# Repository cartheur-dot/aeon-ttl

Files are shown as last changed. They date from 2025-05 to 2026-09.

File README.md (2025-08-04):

## aeon-ttl

The most beautiful machine not only for its pure simplicity.

### References

* RAM[7400](https://github.com/emotional-toys/RAM7400)
* ideal-game-[ttl](https://github.com/emotional-toys/ideal-game-ttl)

### Endeavor

A design for a state-determinate system worthy of what started in September 2023 [here](/Starting.md).

### Relations

This repo is a part of the initiatives described in [this](https://github.com/emotional-toys/RAM7400) repository.

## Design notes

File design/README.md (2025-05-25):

## The aeon-ttl design

Words.

## Build of Materials

An estimate of the first-pass in the design is thus.

| Item # | Component | Part Number | Quantity | Description | Approx. Unit Cost (USD) | Approx. Total Cost (USD) |
|:---:|:---:|:---:|:---:|:---:|:---:|:---:|
| 1 | SRAM (4-bit) | 2114N or equivalent | 1 | 1024x4-bit SRAM (using 16 addresses) | $2.50 | $2.50 |
| 2 | 4-bit Counter | 74LS161 | 1 | Synchronous 4-bit binary counter | $0.80 | $0.80 |
| 3 | 4-bit Register | 74LS173 | 1 | 4-bit D-type register | $1.00 | $1.00 |
| 4 | 555 Timer | NE555P | 1 | Timer IC for clock generation | $0.50 | $0.50 |
| 5 | NAND Gate IC | 74LS00 | 1 | Quad 2-input NAND gate for control logic | $0.60 | $0.60 |
| 6 | AND Gate IC | 74LS08 | 1 | Quad 2-input AND gate for control logic | $0.60 | $0.60 |
| 7 | Inverter IC | 74LS04 | 1 | Hex inverter for control logic | $0.50 | $0.50 |
| 8 | D Flip-Flop | 74LS74 | 1 | Dual D flip-flop for read/write toggle | $0.60 | $0.60 |
| 9 | SPST Switch | Generic | 5 | Single-pole single-throw switches (4 for data input, 1 for R/W) | $0.30 | $1.50 |
| 10 | LED | Generic (Red) | 4 | Indicator LEDs for 4-bit data output | $0.10 | $0.40 |
| 11 | Resistor (10kΩ) | Generic | 5 | Pull-down resistors for switches | $0.05 | $0.25 |
| 12 | Resistor (330Ω) | Generic | 4 | Current-limiting resistors for LEDs | $0.05 | $0.20 |
| 13 | Capacitor (0.1µF) | Generic | 2 | Decoupling capacitors for ICs | $0.10 | $0.20 |
| 14 | Capacitor (10µF)  | Generic | 1 | Timing capacitor for 555 timer | $0.15 | $0.15 |
| 15 | Resistor (1kΩ) | Generic | 2 | Timing resistors for 555 timer | $0.05 | $0.10 |
| 16 | Power Supply | Generic | 1 | 5V DC power supply or regulator (e.g., 7805) | $1.00 | $1.00 |
| 17 | Breadboard | Generic | 1 | Prototyping board for assembly | $5.00 | $5.00 |
| 18 | Jumper Wires | Generic | 50 | Connecting wires for breadboard | $0.05 | $2.50 |

Total Estimated Cost: $16.90.

### Adding base-5 to the mix

* IC1: 2114 SRAM (1024x4-bit, 18-pin DIP).
* IC2: 74LS173 (4-bit D-type register).
* IC3: NE555 (timer for 1 kHz clock).
* IC4: 74LS00 (quad 2-input NAND).
* IC5: 74LS08 (quad 2-input AND).
* IC6: 74LS04 (hex inverter).
* IC7–IC10: 74LS47 (BCD-to-7-segment decoders, 4 units).
* IC11–IC12: 74LS157 (quad 2-to-1 multiplexers, 2 units).
* IC13: 27C16 (2Kx8 ROM for base-5 conversion).
* SW1–SW8: SPST switches (address input, A0–A7).
* SW9–SW12: SPST switches (data input, D0–D3).
* SW13: SPST switch (read/program, R/W).
* SW14: SPST switch (address/data display select).
* LED1–LED12: LEDs (8 yellow for address, 4 orange for data).
* DISP1–DISP4: Common-anode 7-segment displays.
* R1–R13: 10 kΩ resistors (pull-down for switches).
* R14–R25: 330 Ω resistors (LED current-limiting).
* R26–R27: 1 kΩ resistors (555 timer).
* C1: 0.68 µF capacitor (555 timer for 1 kHz).
* C2–C4: 0.1 µF capacitors (decoupling for ICs).
* C5: 10 µF capacitor (555 timer).
* PWR: 5V DC power supply.

| Components | On-Hand |
|:---:|:---:|
| IC1: 2114 SRAM (1024x4-bit, 18-pin DIP). | X |
| IC2: 74LS173 (4-bit D-type register). | |
| IC3: NE555 (timer for 1 kHz clock). | X |
| IC4: 74LS00 (quad 2-input NAND). | X |
| IC5: 74LS08 (quad 2-input AND). | X |
| IC6: 74LS04 (hex inverter). | X |
| IC7–IC10: 74LS47 (BCD-to-7-segment decoders, 4 units).  | |
| IC11–IC12: 74LS157 (quad 2-to-1 multiplexers, 2 units). | |
| IC13: 27C16 (2Kx8 ROM for base-5 conversion). | X |
| SW1–SW8: SPST switches (address input, A0–A7). | X |
| SW9–SW12: SPST switches (data input, D0–D3). | X |
| SW13: SPST switch (read/program, R/W). | X |
| SW14: SPST switch (address/data display select). | X |
| LED1–LED12: LEDs (8 yel for address, 4 oran for data).  | X |
| DISP1–DISP4: Common-anode 7-segment displays. | X |
| R1–R13: 10 kΩ resistors (pull-down for switches). | X |
| R14–R25: 330 Ω resistors (LED current-limiting). | X |
| R26–R27: 1 kΩ resistors (555 timer). | X |
| C1: 0.68 µF capacitor (555 timer for 1 kHz). | |
| C2–C4: 0.1 µF capacitors (decoupling for ICs). | X |
| C5: 10 µF capacitor (555 timer). | X |
| PWR: 5V DC power supply. | X |

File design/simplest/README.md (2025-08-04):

## Simplest of them all

### References

* RAM[7400](https://github.com/emotional-toys/RAM7400)
* ideal-game-[ttl](https://github.com/emotional-toys/ideal-game-ttl)

### The state-determinate system

_Summary_

* Handles 4-bit data (D0–D3) with 8-bit addressing (A0–A7) using a single 2114 RAM (1K x 4-bit).
* Uses a 1 kHz clock from a 555 timer, pausable via an SPST switch for debugging.
* Features SPST switches for 8-bit address (A0–A7), 4-bit data (D0–D3), and read/write control.
* Displays 4-bit data on LEDs (input during write, output during read).
* Uses a LOAD pushbutton to trigger read/write operations.
* Uses 74LS00 for debouncing the LOAD button (no 74LS132 available).
* Minimizes ICs: 2114, 74LS244, 555 timer, 74LS00 (4 ICs total).

Key Changes from [this](/design/PROCESS.md)

* Reverts to single 2114 RAM for 4-bit data (D0–D3), as you specified only enough SPST switches for 4-bit data.
* Adds SPST pause switch for the 555 timer (controls reset pin).
* Continues using 74LS00 for debouncing, with the same circuit as before.
* Uses eight SPST switches for addressing (A0–A7), four SPST switches for data (D0–D3), one SPST for read/write, and one pushbutton for LOAD.
* 74LS244 buffers only 4-bit data (uses half the IC, leaving the second buffer set unused).

_Build of materials_

| Component |  Quantity | Description | Notes |
|:---:|:---:|:---:|:---:|
| 2114 RAM | 1 | 1K x 4-bit static RAM (18-pin DIP) | Stores 4-bit data (D0–D3) |
| 74LS244 | 1 | Octal buffer/line driver (20-pin DIP) | Buffers 4-bit data (D0–D3) |
| 555 Timer | 1 | Timer IC (8-pin DIP) | Generates 1 kHz clock, pausable |
| 74LS00 | 1 | Quad 2-input NAND gate (14-pin DIP) | Debounces LOAD button, generates control signals |
| SPST Switches | 14 | Single-pole single-throw switches | 8 address (A0–A7), 4 data (D0–D3), 1 R/W', 1 pause |
| Pushbutton (LOAD) | 1 | Momentary SPST pushbutton | Triggers read/write operation |
| LEDs | 4 | Standard LEDs (e.g., 5mm, red) | Display 4-bit data (D0–D3) |
| Resistors (10 kΩ) | 14 | Pull-down/pull-up resistors | 8 address, 4 data, 1 R/W', 1 pause, 2 debounce |
| Resistors (220 Ω) | 4 | Current-limiting resistors for LEDs | Limit LED current to ~20 mA |
| Resistor (1 kΩ) | 1 | For 555 timer (R1) | Sets 1 kHz clock frequency |
| Resistor (680 kΩ) | 1 | For 555 timer (R2) | Sets 1 kHz clock frequency |
| Capacitor (1 µF) | 1 | For 555 timer | Sets 1 kHz clock frequency |
| Capacitor (0.1 µF)  | 3 | Decoupling (2) and debounce (1) | For U1, U2/U3/U4, and LOAD button |
| Capacitor (0.01 µF) | 1 | For 555 timer control | Stabilizes timer operation |
| Power Supply | 1 | +5V DC power supply | Powers all ICs and LEDs |

_Notes_

For KiCad, the DigiKey site has the 2114 listed as MD2114AL3. Models are [here](https://github.com/cartheur-forks/digikey-kicad-library).

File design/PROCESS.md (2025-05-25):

# 8-Bit Addressing, 4-Bit Data SRAM Interface Schematic and ROM Contents

This document describes a schematic for a digital logic circuit that interfaces an 8-bit address, 4-bit data system with SRAM, using SPST switches for input, LEDs for state indication, a 1 kHz clock, a read/program switch, and a four 7-segment display for base-5 output. It also specifies the ROM contents for binary-to-base-5 conversion to drive the display.

## Design Specifications
- **Addressing**: 8-bit address bus (256 locations) via 8 SPST switches.
- **Data**: 4-bit data bus via 4 SPST switches.
- **RAM**: 4-bit SRAM (e.g., 2114, using 256 of 1024 locations).
- **Indicators**: 12 LEDs (8 for address, 4 for data) to show binary state (0 or 1).
- **Display**: Four 7-segment displays showing address (0–255) or data (0–15) in base-5, selected by an SPST switch.
- **Control**: Read/program SPST switch for read/write operations.
- **Clock**: 1 kHz from a 555 timer for synchronous operation.

## Schematic Description

### Components
From the updated Bill of Materials (BoM):

| Item | Component | Part Number | Quantity | Description |
|---|---|---|---|---|
| IC1 | SRAM (4-bit) | 2114N | 1 | 1024x4-bit SRAM (using 256 addresses) |
| IC2 | 4-bit Register | 74LS173 | 1 | 4-bit D-type register for data |
| IC3 | 555 Timer | NE555P | 1 | Timer IC for 1 kHz clock |
| IC4 | NAND Gate IC | 74LS00 | 1 | Quad 2-input NAND for control logic |
| IC5 | AND Gate IC | 74LS08 | 1 | Quad 2-input AND for control logic |
| IC6 | Inverter IC | 74LS04 | 1 | Hex inverter for control logic |
| IC7–IC10 | BCD-to-7-Segment Decoder | 74LS47 | 4 | Decoders for base-5 display |
| IC11–IC12 | Multiplexer | 74LS157 | 2 | Quad 2-to-1 multiplexers for address/data display switch |
| IC13 | ROM | 27C16 | 1 | 2Kx8 ROM for binary-to-base-5 conversion |
| SW1–SW8 | SPST Switch | Generic | 8 | Address input (A0–A7) |
| SW9–SW12 | SPST Switch | Generic | 4 | Data input (D0–D3) |
| SW13 | SPST Switch | Generic | 1 | Read/program (R/W) |
| SW14 | SPST Switch | Generic | 1 | Address/data display select |
| LED1–LED12 | LED (Red) | Generic | 12 | LEDs for 8 address, 4 data lines |
| R1–R13 | Resistor (10 kΩ) | Generic | 13 | Pull-down resistors for switches |
| R14–R25 | Resistor (330 Ω) | Generic | 12 | Current-limiting resistors for LEDs |
| C1 | Capacitor (0.68 µF) | Generic | 1 | Timing capacitor for 555 timer (1 kHz) |
| C2–C4 | Capacitor (0.1 µF) | Generic | 3 | Decoupling capacitors for ICs |
| C5 | Capacitor (10 µF) | Generic | 1 | Timing capacitor for 555 timer |
| R26–R27 | Resistor (1 kΩ) | Generic | 2 | Timing resistors for 555 timer |
| PWR | Power Supply | Generic | 1 | 5V DC power supply |
| DISP1–DISP4 | 7-Segment Display | Generic | 4 | Common-anode displays for base-5 output |

**Total Estimated Cost**: ~$31.50 (based on 2025 prices from DigiKey/Mouser).

### Connections

1. **Power and Ground**:
   - Connect Vcc (5V) and GND to all ICs:
     - **IC1 (2114)**: Pin 18 (Vcc), Pin 9 (GND).
     - **IC2 (74LS173)**: Pin 16 (Vcc), Pin 8 (GND).
     - **IC3 (NE555)**: Pin 8 (Vcc), Pin 1 (GND).
     - **IC4 (74LS00)**: Pin 14 (Vcc), Pin 7 (GND).
     - **IC5 (74LS08)**: Pin 14 (Vcc), Pin 7 (GND).
     - **IC6 (74LS04)**: Pin 14 (Vcc), Pin 7 (GND).
     - **IC7–IC10 (74LS47)**: Pin 16 (Vcc), Pin 8 (GND).
     - **IC11–IC12 (74LS157)**: Pin 16 (Vcc), Pin 8 (GND).
     - **IC13 (27C16)**: Pin 24 (Vcc), Pin 12 (GND).
   - Place 0.1 µF capacitors (C2–C4) between Vcc and GND near IC1, IC2, and IC13.

2. **Address Input (SW1–SW8)**:
   - Connect 8 SPST switches (SW1–SW8) to 5V (ON = 1) or GND via 10 kΩ resistors (R1–R8) for A0–A7.
   - Outputs to:
     - **IC1 (2114)**: A0–A7 (Pins 1–8).
     - **LED1–LED8**: Anodes via 330 Ω resistors (R14–R21); cathodes to GND.
     - **IC11–IC12 (74LS157)**: Inputs A0–A7 (IC11: Pins 2, 5, 11, 14; IC12: Pins 2, 5, 11, 14).

3. **Data Input/Output (SW9–SW12, IC2, LED9–LED12)**:
   - Connect 4 SPST switches (SW9–SW12) to 5V or GND via 10 kΩ resistors (R9–R12) for D0–D3.
   - Outputs to **IC2 (74LS173)**: D0–D3 (Pins 3, 4, 5, 6).
   - IC2 Q0–Q3 (Pins 14, 13, 12, 11) to:
     - **IC1 (2114)**: D0–D3 (Pins 10–13).
     - **LED9–LED12**: Anodes via 330 Ω resistors (R22–R25); cathodes to GND.
     - **IC11 (74LS157)**: Inputs B0–B3 (Pins 3, 6, 12, 15).
   - IC2 clock (Pin 7) to IC3 (NE555) Pin 3.
   - Tie IC2 OE1, OE2 (Pins 9, 10) to GND; clear (Pin 15) to 5V.

4. **Clock (IC3)**:
   - Configure **IC3 (NE555)** in astable mode (~1 kHz):
     - Pin 2 (TRIG), Pin 6 (THR) to C1 (0.68 µF) to GND.
     - Pin 6 to Pin 7 (DISCH) via R26 (1 kΩ).
     - Pin 7 to 5V via R27 (1 kΩ).
     - Pin 5 (CONT) to C5 (10 µF) to GND.
     - Pin 3 (OUT) to IC2 Pin 7 and control logic.
   - Frequency: f ≈ 1.44 / ((R26 + 2×R27) × C1) ≈ 1 kHz.

5. **Control Logic (IC4, IC5, IC6, SW13)**:
   - Connect **SW13** (read/program) to 5V (read = 1) or GND via R13 (program = 0).
   - **Write Enable (WE)**:
     - SW13 to **IC4 (74LS00)** Pin 1.
     - IC3 Pin 3 to IC4 Pin 2.
     - IC4 Pin 3 to **IC1 (2114)** WE (Pin 17, active low).
   - **Output Enable (OE)**:
     - SW13 to **IC6 (74LS04)** Pin 1.
     - IC6 Pin 2 to **IC5 (74LS08)** Pin 1.
     - IC3 Pin 3 to IC5 Pin 2.
     - IC5 Pin 3 to **IC1 (2114)** OE (Pin 15, active low).
   - **Chip Enable (CE)**: Tie IC1 Pin 16 to GND (always active).

6. **Display (IC7–IC10, IC11–IC12, IC13, DISP1–DISP4, SW14)**:
   - **Address/Data Select**:
     - **SW14** to 5V (address = 1) or GND (data = 0) via 10 kΩ resistor.
     - SW14 to **IC11–IC12 (74LS157)** select pins (Pin 1).
   - **Address Inputs**:
     - SW1–SW8 (A0–A7) to IC11–IC12 inputs A0–A7.
   - **Data Inputs**:
     - IC2 Q0–Q3 to IC11 inputs B0–B3; tie IC12 B4–B7 to GND.
   - **Multiplexer Outputs**:
     - IC11–IC12 Y0–Y7 to **IC13 (27C16)** A0–A7 (Pins 2, 3, 4, 5, 6, 7, 8, 9).
   - **ROM**:
     - IC13 D0–D7 (Pins 11, 13, 15–20) to **IC7–IC10 (74LS47)** BCD inputs (A–D, Pins 7, 1, 2, 6).
     - Tie IC13 A8–A10 (Pins 10, 21, 23), CE (Pin 22), OE (Pin 20) to GND.
   - **7-Segment Displays**:
     - IC7–IC10 outputs a–g to DISP1–DISP4 segments a–g (optional 330 Ω resistors).
     - DISP1–DISP4 common anodes to 5V.
     - Tie IC7–IC10 LT (Pin 3), BI (Pin 4), RBI (Pin 5) to 5V.

## Operation
- **Write**:
  - Set SW1–SW8 (e.g., 00000011 = 3), SW9–SW12 (e.g., 1011 = 11), SW13 to program (0).
  - Clock pulse: WE = Low, OE = High; 1011 written to RAM at address 3.
  - LED1–LED8 show 00000011, LED9–LED12 show 1011.
  - SW14 selects address (2010 in base-5) or data (30 in base-5) on DISP1–DISP4.
- **Read**:
  - Set SW1–SW8 (e.g., 00000011), SW13 to read (1).
  - Clock pulse: WE = High, OE = Low; RAM outputs 1011 to IC2.
  - LED1–LED8 show 00000011, LED9–LED12 show 1011.
  - SW14 selects address (2010 in base-5) or data (30 in base-5) on DISP1–DISP4.

## ROM Contents for Base-5 Conversion
The **27C16 ROM** (2Kx8) converts 8-bit binary inputs (0–255) to base-5 digits for the four 7-segment displays. Data (0–15) requires two digits (00–30); addresses (0–255) require four digits (0000–2010).

### Conversion Logic
- **Data (0–15)**: Maps to base-5 00–30 (e.g., 15 = 3×5¹ + 0 = 30).
- **Address (0–255)**: Maps to base-5 0000–2010 (e.g., 255 = 2×5³ + 0×5² + 1×5¹ + 0 = 2010).
- Each ROM address outputs two BCD digits (8 bits: D7–D4 = digit 1, D3–D0 = digit 0).
- Use two ROM accesses per address input:
  - Address N (0x00–0xFF): Outputs digits d₁, d₀.
  - Address N+256 (0x100–0x1FF): Outputs digits d₃, d₂.

### ROM Table (Partial)
| ROM Address (Hex) | Input (Binary) | Base-5 Value | Output (BCD, D7–D0) | Display Digits |
|---|---|---|---|---|
| 00 | 00000000 (0) | 00 | 0000 0000 | 0 0 |
| 01 | 00000001 (1) | 01 | 0000 0001 | 0 1 |
| 02 | 00000010 (2) | 02 | 0000 0010 | 0 2 |
| ... | ... | ... | ... | ... |
| 0F | 00001111 (15)  | 30 | 0011 0000 | 3 0 |
| 10 | 00010000 (16)  | 31 | 0011 0001 | 3 1 |
| ... | ... | ... | ... | ... |
| FF | 11111111 (255) | 2010 | 0010 0000 | 2 0* |
| 100 | 00000000 (0) | 00 | 0000 0000 | 0 0 |
| ... | ... | ... | ... | ... |
| 1FF | 11111111 (255) | 2010 | 0001 0000 | 1 0* |

*Note*: For addresses, ROM[0xFF] gives digits 1–2 (20), ROM[0x1FF] gives digits 3–4 (10). Toggle A8 (IC13 Pin 10) via control logic or a switch to select digit pairs.

### Programming the ROM
- **Size**: Use 512 bytes (0x00–0x1FF) of the 27C16’s 2048 bytes.
- **Algorithm**:
  - For input N (0–255):
    - Compute base-5: N = d₃×5³ + d₂×5² + d₁×5¹ + d₀×5⁰ (d₀–d₃ = 0–4).
    - Store d₁, d₀ as BCD in ROM[N].
    - Store d₃, d₂ as BCD in ROM[N+256].
  - Example: N = 255 → 2010 (base-5):
    - d₃ = 2, d₂ = 0, d₁ = 1, d₀ = 0.
    - ROM[0xFF] = 0010 0000 (2 0).
    - ROM[0x1FF] = 0001 0000 (1 0).
- **Tool**: Use a programmer (e.g., TL866II) to burn the ROM. Generate the 512-byte binary file with a script (e.g., Python):

```python
rom = bytearray(512)
for n in range(256):
    d3 = n // 125  # 5^3
    n %= 125
    d2 = n // 25   # 5^2
    n %= 25
    d1 = n // 5    # 5^1
    d0 = n % 5     # 5^0
    rom[n] = (d1 << 4) | d0
    rom[n + 256] = (d3 << 4) | d2
with open("rom.bin", "wb") as f:
    f.write(rom)

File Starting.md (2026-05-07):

## A 4-Bit Logical Revolver with SRAM

This document describes a 4-bit logic system, known as a _revolver_ with memory, serving as the backplane of an embodied intelligent system. In summary: Satisfation of the linear behavior matrix construct for artificial (and real) self-contained systems.

## Circuit Overview
The circuit uses a 4-bit counter to generate addresses, a 4-bit register for data input/output, and logic gates for control signals. It operates synchronously with a clock for proper timing.

## Components
1. **RAM Chip**:
   - **Example**: 2114 SRAM (1024x4-bit, using only 16 addresses).
   - **Specs**: 4-bit data bus, 10-bit address bus (using 4 bits), control signals (CE, WE, OE).
2. **4-Bit Binary Counter**:
   - **Example**: 74LS161 (synchronous 4-bit binary counter).
   - **Purpose**: Generates 4-bit addresses (A0–A3) for 16 memory locations.
3. **4-Bit Data Register**:
   - **Example**: 74LS173 (4-bit D-type register).
   - **Purpose**: Holds data for writing to RAM or stores data read from RAM.
4. **Clock Source**:
   - **Example**: 555 timer or crystal oscillator (e.g., 1 MHz).
   - **Purpose**: Synchronizes the counter and register.
5. **Control Logic**:
   - **Components**: 74LS00 (quad NAND gates), 74LS08 (quad AND gates).
   - **Purpose**: Generates control signals (CE, WE, OE) based on read/write selector.
6. **Read/Write Selector**:
   - **Example**: Manual switch or 74LS74 D flip-flop.
   - **Purpose**: Selects read or write operation.
7. **Input Switches**:
   - Four SPST switches for 4-bit data input.
   - **Purpose**: Sets data to write to RAM.
8. **Output Display**:
   - **Example**: Four LEDs or 7-segment display with 74LS47 decoder.
   - **Purpose**: Displays 4-bit data read from RAM.
9. **Pull-up/down Resistors**:
   - **Example**: 10kΩ resistors.
   - **Purpose**: Stabilizes inputs and prevents floating signals.
10. **Power Supply**:
    - 5V DC for TTL logic chips.

## Circuit Connections
1. **RAM (2114 SRAM)**:
   - **Address Lines (A0–A3)**: Connect to 74LS161 counter outputs (Q0–Q3). Ground unused address lines (A4–A9).
   - **Data Lines (D0–D3)**: Connect bidirectionally to 74LS173 register outputs (Q0–Q3) for writing and inputs (D0–D3) for reading.
   - **Control Lines**:
     - **CE (Chip Enable)**: Tie to ground (active low) or control logic output.
     - **WE (Write Enable)**: Connect to control logic (active low for write).
     - **OE (Output Enable)**: Connect to control logic (active low for read).
   - **Power**: Vcc to 5V, GND to ground.

2. **4-Bit Counter (74LS161)**:
   - **Clock Input**: Connect to clock source (e.g., 555 timer).
   - **Outputs (Q0–Q3)**: Connect to RAM address lines (A0–A3).
   - **Enable Inputs (ENP, ENT)**: Tie to Vcc for continuous counting.
   - **Clear**: Tie to Vcc or reset button (to ground).
   - **Power**: Vcc to 5V, GND to ground.

3. **4-Bit Data Register (74LS173)**:
   - **Data Inputs (D0–D3)**: Connect to switches (write) or RAM data lines (read).
   - **Data Outputs (Q0–Q3)**: Connect to RAM data lines (write) and LEDs/display (read).
   - **Clock Input**: Connect to clock source.
   - **Output Enable (OE1, OE2)**: Tie to ground or control logic.
   - **Power**: Vcc to 5V, GND to ground.

4. **Control Logic**:
   - Use a switch or 74LS74 flip-flop for read/write signal (R/W).
   - **Write (R/W = 0)**:
     - WE = (R/W NAND Clock) via 74LS00.
     - OE = High (disabled) via inverter (e.g., 74LS04).
     - CE = Low (active).
   - **Read (R/W = 1)**:
     - WE = High (disabled).
     - OE = (R/W AND Clock) via 74LS08.
     - CE = Low (active).
   - **Note**: CE can be tied low for simplicity.

5. **Clock Source (555 Timer)**:
   - Configure in astable mode (~1 Hz to 1 MHz, adjustable).
   - Output connects to counter and register clock inputs.

6. **Input/Output**:
   - **Input**: Four switches to data register inputs (D0–D3) via 10kΩ pull-down resistors.
   - **Output**: Four LEDs (via 330Ω resistors) or 7-segment display with 74LS47.

## Operation
1. **Initialization**:
   - Power on (5V).
   - Reset counter (74LS161) to address 0 if needed.

2. **Write Operation**:
   - Set R/W switch to write (R/W = 0).
   - Set switches to 4-bit data (e.g., 1011).
   - On clock pulse:
     - Counter outputs address (e.g., 0000).
     - Register loads switch data (1011).
     - Control logic: CE = Low, WE = Low, OE = High.
     - RAM stores 1011 at address 0000.
     - Counter increments to next address.

3. **Read Operation**:
   - Set R/W switch to read (R/W = 1).
   - On clock pulse:
     - Counter outputs address (e.g., 0000).
     - Control logic: CE = Low, WE = High, OE = Low.
     - RAM outputs data (e.g., 1011) to data lines.
     - Register captures data and displays on LEDs (e.g., ON-OFF-ON-ON).
     - Counter increments to next address.

4. **Continuous Operation**:
   - Clock cycles counter through addresses (0000 to 1111).
   - R/W switch determines read or write.

## Timing Considerations
- **Clock Speed**: Match RAM access time (e.g., 200 ns for 2114). Use slow clock (e.g., 1 kHz) for debugging.
- **Setup/Hold Times**: 74LS161/74LS173 ensure stable signals.
- **Control Timing**: Synchronize WE/OE with clock to avoid glitches.

## Example Signal Flow
### Write at Address 0000
- Clock pulse triggers.
- Counter outputs 0000.
- Switches set to 1011, loaded into register.
- R/W = 0: WE = Low, OE = High, CE = Low.
- RAM stores 1011 at 0000.
- Counter increments to 0001.

### Read at Address 0000
- Clock pulse triggers.
- Counter outputs 0000.
- R/W = 1: WE = High, OE = Low, CE = Low.
- RAM outputs 1011.
- Register captures 1011, displays on LEDs.
- Counter increments to 0001.

## Notes
- **Scalability**: Extend address bus (e.g., A4–A9) for full 2114 RAM access (1024 locations).
- **Simplifications**: Tie CE low; use manual clock (push-button) for step-by-step operation.
- **Debugging**: Use logic probe/oscilloscope to verify signals.
- **Alternatives**: Use CMOS chips (e.g., 74HC161, 74HC173) for TTL compatibility.

This circuit is a minimal design for educational purposes or simple applications like data logging. For a schematic or further details, please specify!

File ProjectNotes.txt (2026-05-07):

May 2025
Project notes for aeon-ttl

23.05.2025
    1015: A design worhty of what started in September 2023 starts here.
    1140: Printing a pair of 4-bit LED indicators from the 4-bit seitch pattern inspired by the Rodney method.
24.05.2025
    1151: Creating a stacked LED-4-bit combo for the data area of programming, since it is impossible to reuse either switches or lamps.
    2004: Adjusting the models to fit the switch diameter and number, since I need a R/P switch also.
    2011: Done and found the 4-segment display I ordered in 2021. probably in a box that is unopened. This will round-out the bph base-5 display per either the address or the data or both - not sure exactly just yet but think what is being printed is sufficient. What I said the last time...
    2017: Made one with the a-ds-display switch to check base-5 on address and data.
25.05.2025
    1435: Want to spend this session with the first-draft circuit design and glue in-place the UI compoenents.
    1531: Short a few ICs and money not in account yet. It seems to me including the base-5 will bring us around to the right place and see where the innovation of the circuit through its ideal paces lies. Or maybe I've been just making up shit since 1997.
    1534: Next step is design and to pull the parts that I have in-stock.
    1837: What I printed: Added the bezels and switches, set in glue to await tomorrow's ambitions.
26.05.2025
    1046: Getting boggled by KiCad and old symbols, where Rodney seemed like a dream. Maybe hand-drawing the schematic seems good but think I will need to create a part.
    1301: After a lot of noise, settled onto Multisim to get the schematic drafted.
    1435: Over here on amd64 linux with seven to continue the great work in MultiSim.
    1806: Fitted a-new Henry with a 5Ah battery for use with the Juice. Next session will get it cleaned-up and fitted.
13.06.2025
    2041: Tracing my way back from where I have been distracted. Got a bear ready for assembly but stopped installing the PI. Something froze in m.e. Dunno what happened between 1436 and 1805 of the last entry.
07.05.2026
    1835: Consolidating around dot.

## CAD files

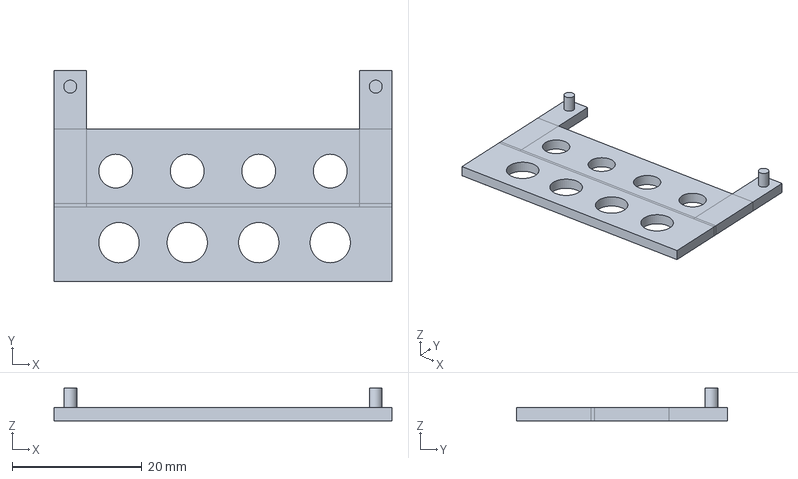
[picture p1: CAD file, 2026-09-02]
design/4-bit-input-pb/switches-indicator-four.FCStd
52.0 x 32.5 x 5.00 mm

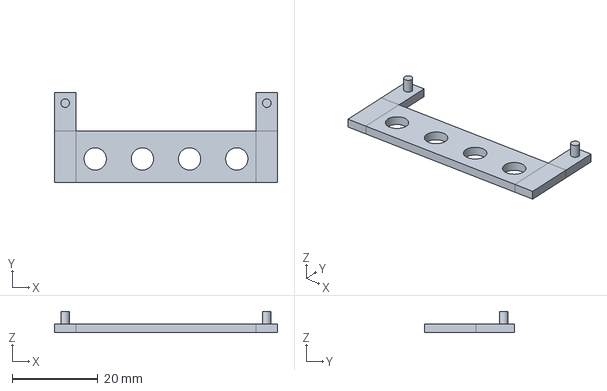
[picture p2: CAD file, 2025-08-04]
design/4-bit-input/4-bit-switcher.FCStd
52.0 x 21.0 x 5.00 mm

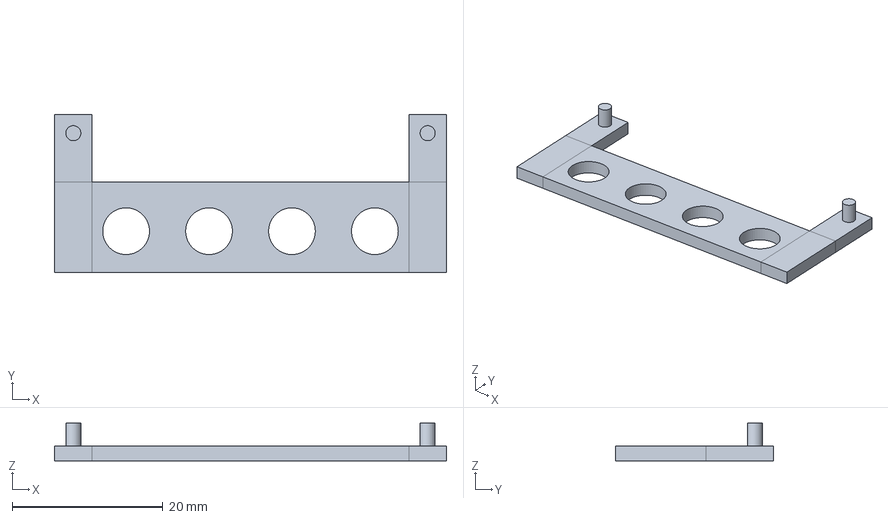
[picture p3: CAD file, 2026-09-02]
design/led-indicator/led-indicator-four.FCStd
52.0 x 21.0 x 5.00 mm

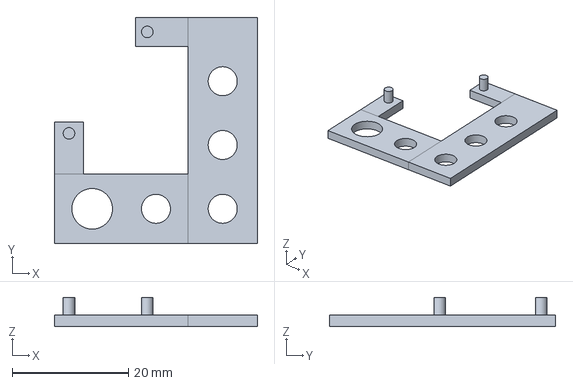
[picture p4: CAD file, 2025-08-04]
design/4-bit-input-pb/4-bit-switch-pb.FCStd
35.0 x 39.0 x 5.00 mm

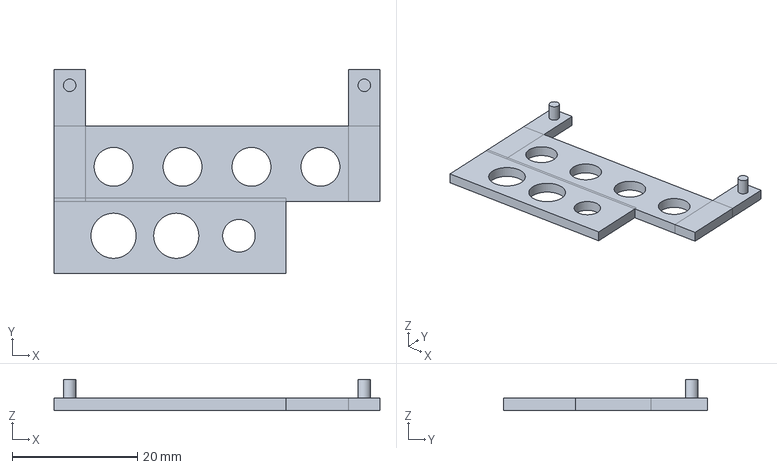
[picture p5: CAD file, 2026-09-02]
design/led-indicator/led-indicator-2pb-switch.FCStd
52.0 x 32.5 x 5.00 mm

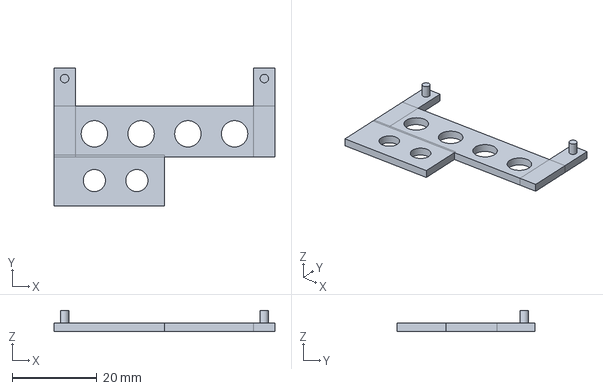
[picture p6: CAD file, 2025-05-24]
design/led-indicator/led-indicator-switch-two.FCStd
52.0 x 32.5 x 5.00 mm

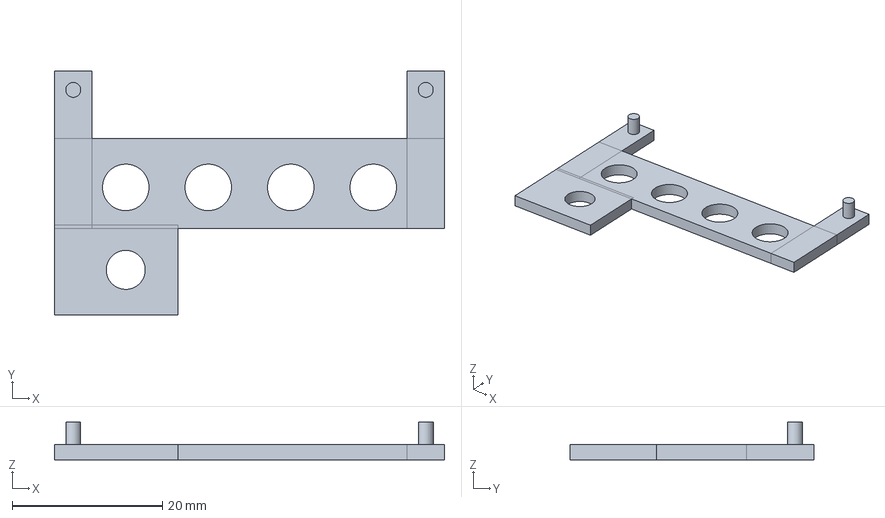
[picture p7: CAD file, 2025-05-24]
design/led-indicator/led-indicator-switch.FCStd
52.0 x 32.5 x 5.00 mm

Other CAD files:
design/led-indicator/led-indicator-three.FCStd
design/led-indicator/led-indicator-switches.FCStd
design/led-indicator/led-indicator.FCStd
design/4-bit-input-pb/4-bit-switch-pb.stl
design/4-bit-input-pb/switches-indicator-four.stl
design/4-bit-input/4-bit-switcher.stl
design/led-indicator/led-indicator-2pb-switch.stl
design/led-indicator/led-indicator-four.stl
design/led-indicator/led-indicator-switch-two.stl
design/led-indicator/led-indicator-switch.stl
design/led-indicator/led-indicator-switches.stl
design/led-indicator/led-indicator-three.stl

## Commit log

2025-05-23 Add led indicator
    [led-indicator.FCStd]
2025-05-23 Add modified 4-bit design for LEDs
    [led-indicator.FCStd, led-indicator.stl]
2025-05-23 Add FF print file
2025-05-23 Add to design
    [4-bit-switch-pb.FCStd, 4-bit-switch-pb.stl, 4-bit-switcher.FCStd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]
2025-05-23 Enlarge holes by 0.10
    [led-indicator.FCStd, led-indicator.stl]
2025-05-24 Create model
    [led-indicator-switches.FCStd, led-indicator-switches.stl]
2025-05-24 Add model
    [4-bit-switcher.FCStd, led-indicator-switch.FCStd, led-indicator-switch.stl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]
2025-05-24 Add print file
2025-05-24 Add print
2025-05-25 Add KiCad model lib for 2114
2025-05-25 Add project
    [dot_expression.kicad_pcb, dot_expression.kicad_sch]
2025-05-26 Add draft circuit design
2025-05-26 Add entry
    [dot_expression.kicad_sch]
2025-08-04 Clean model
    [4-bit-switch-pb.FCStd, 4-bit-switcher.FCStd, 4-bit-switcher.stl]
2026-09-02 Llimit scope design
    [led-indicator-2pb-switch.FCStd, led-indicator-2pb-switch.stl, led-indicator-four.FCStd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]
